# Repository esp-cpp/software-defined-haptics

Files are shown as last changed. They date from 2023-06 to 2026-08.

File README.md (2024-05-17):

# Software Defined Haptics

This project contains the MCAD and source files for a BLDC motor test stand,
designed to enable running various experiments in openloop control, closed loop
control, and user interface / haptics using a small BLDC motor that's commonly
used in camera gimbals.

The code supports running on the custom BLDC Test Stand (`TinyS3 Test Stand`),
as well as on the `MotorGo-Mini`. You can select which hardware you want to run
on via `menuconfig`.

## Hardware

Either:
* TinyS3 Test Stand:
  * TinyS3
  * BLDC Motor (I used [these A and B motors](https://www.aliexpress.us/item/3256802907900422.html) from aliexpress)
  * MT6701 Magnetic Encoder Breakout (I used [this purple one (color B)](https://www.aliexpress.us/item/3256804851103272.html) from aliexpress)
  * TMC6300 BOB
  * Mini solderless breadboard
  * 3d printed test stand enclosure (.stl and source files in the [mcad](./mcad) directory)
  * Benchtop power supply (currently running at 5V 1A so many things should work)
or:
* MotorGo-Mini

### Configure

``` 
idf.py menuconfig
```

Select which hardware you are building and deploying to.

### Build and Flash

Build the project and flash it to the board, then run monitor tool to view serial output:

```
idf.py -p PORT flash monitor
```

(Replace PORT with the name of the serial port to use.)

(To exit the serial monitor, type ``Ctrl-]``.)

See the Getting Started Guide for full steps to configure and use ESP-IDF to build projects.

## Output

The haptics (detent configuration, click/buzz) can be configured dynamically at
run-time using the provided CLI, see screenshot below:

CleanShot 2023-06-23 at 13 23 44

https://github.com/esp-cpp/bldc_test_stand/assets/213467/d0974dc0-430a-4957-bd6d-f9841209f21d

As you can see, the cli also allows you to start and stop the haptic engine
(default is off when the program starts) and allows you to query the position of
the motor based on the current detent config. The default detent config is the
unbounded_no_detents configuration.

For more information, see the documentation or the original PR:
https://github.com/esp-cpp/espp/pull/60

Some examples:

### coarse values strong detents (best with sound)

https://github.com/esp-cpp/espp/assets/213467/a256b401-6e45-4284-89c7-2dec9a49daa7

### magnetic detents (best with sound)

https://github.com/esp-cpp/espp/assets/213467/ab1ace5c-f967-4cfc-b304-7736fdb35bcb

### On / Off Strong Detents (best with sound)

https://github.com/esp-cpp/espp/assets/213467/038d79b1-7cd9-4af9-b7e8-1b4daf6a363a

### Multi-rev no detents

https://github.com/esp-cpp/espp/assets/213467/2af81edb-67b8-488b-ae7a-3549be36b8cc

## Troubleshooting

Make sure to run the code once with `zero_electrical_offset` set to 0 so that
the motor will go through a calibration / zero offset routine. At the end of
this startup routine it will print the measured zero electrical offset that you
can then provide within the code, at which point it will not need to run the
calibration routine.

You must run this calibration any time you change your hardware configuration
(such as by remounting your motor, magnet, encoder chip).

## Code Breakdown

This example encapsulates the board support packages into one of two components:
* `espp::TinyS3TestStand` (in this repo)
* `espp::MotorGoMini` (in espp)

These components build complex haptic behavior using the
following components:

* `espp::Mt6701`
* `espp::BldcDriver`
* `espp::BldcMotor`
* `espp::BldcHaptics`
* `espp::I2c`

You combine the `Mt6701` and `BldcDriver` together when creating the `BldcMotor`
and then simply pass the `BldcMotor` to the `BldcHaptics` component. At that
point, you only have to interface to the `BldcHaptics` to read the input
position or reconfigure the haptics.

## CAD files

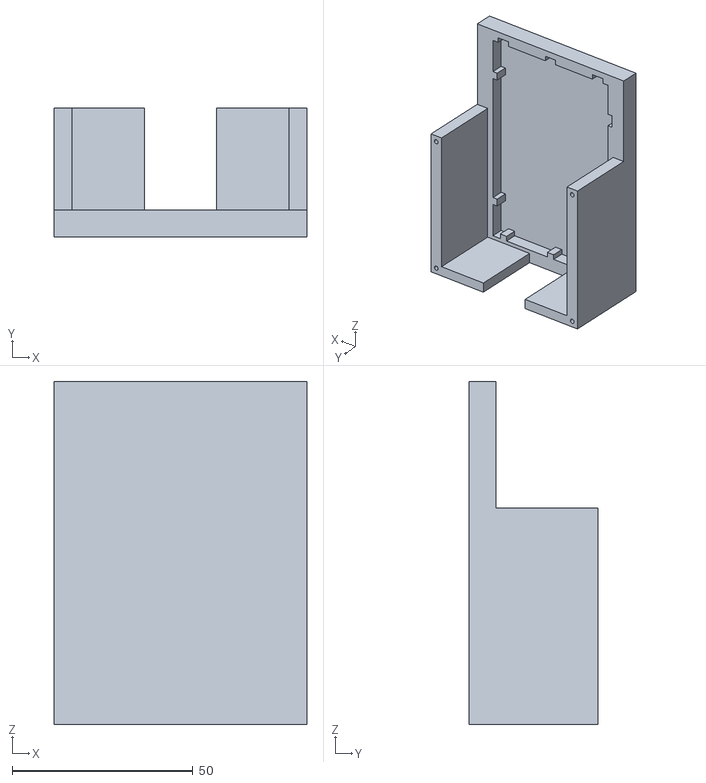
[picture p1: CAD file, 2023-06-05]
mcad/bldc_test_stand_bottom.stl
70.0 x 35.8 x 95.0

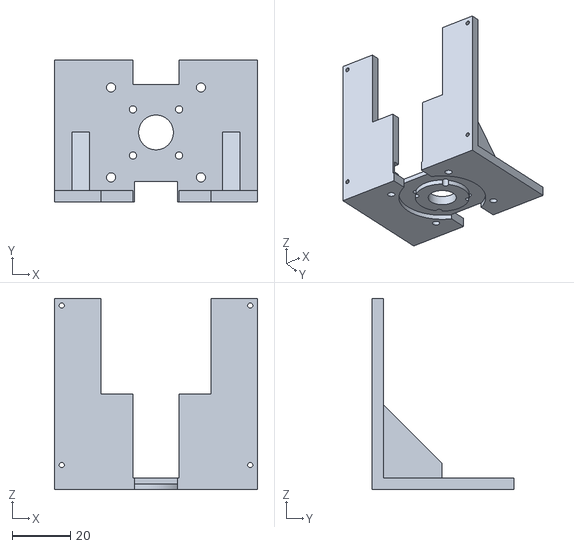
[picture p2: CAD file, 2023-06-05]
mcad/bldc_test_stand_top.stl
70.0 x 49.0 x 66.0

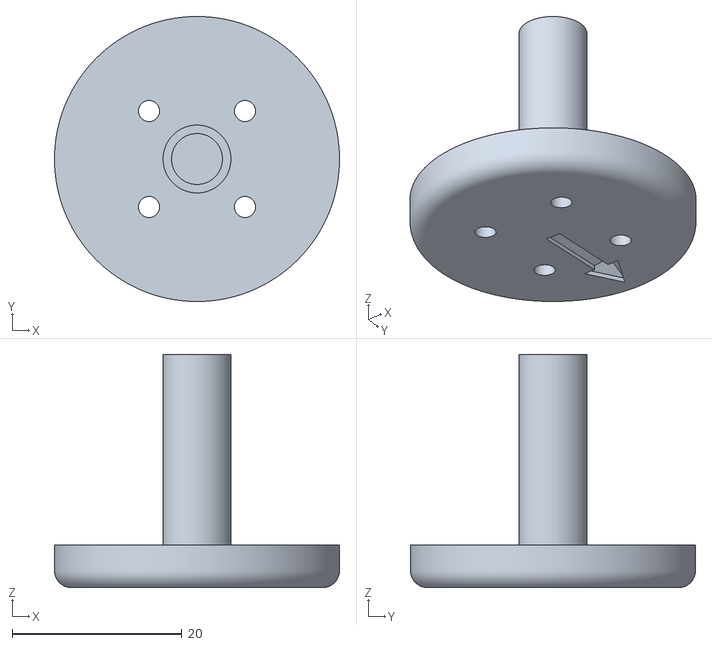
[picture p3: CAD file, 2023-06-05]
mcad/bldc_motor_cap.stl
33.6 x 33.6 x 27.5

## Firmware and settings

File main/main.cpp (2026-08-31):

#include <chrono>
#include <vector>

#include "bldc_haptics.hpp"
#include "cli.hpp"

#include "motorgo-mini.hpp"
#include "tinys3_test_stand.hpp"

using namespace std::chrono_literals;

extern "C" void app_main(void) {
  espp::Logger logger({.tag = "BLDC Test Stand", .level = espp::Logger::Verbosity::DEBUG});

  logger.info("Bootup");

#if CONFIG_EXAMPLE_HARDWARE_MOTORGO_MINI
#pragma message("Using MotorGo Mini hardware configuration")
  logger.info("Using MotorGo Mini hardware configuration");
  // we don't want to init both motors, so we'll pass in auto_init=false
  auto &motorgo_mini = espp::MotorGoMini::get();

#if CONFIG_EXAMPLE_BLDC_MOTOR_1
#pragma message("Using MotorGo Mini Motor 1")
  logger.info("Configuring Motor 1");
  auto motor_config = motorgo_mini.default_motor1_config;
#elif CONFIG_EXAMPLE_BLDC_MOTOR_2
#pragma message("Using MotorGo Mini Motor 2")
  logger.info("Configuring Motor 2");
  auto motor_config = motorgo_mini.default_motor2_config;
#else
#error "No motor selected"
#endif

  // velocity PID config:
  motor_config.velocity_pid_config.kp = 0.010f;
  motor_config.velocity_pid_config.ki = 0.100f;
  motor_config.velocity_pid_config.kd = 0.000f;
  // angle PID config:
  motor_config.angle_pid_config.kp = 5.000f;
  motor_config.angle_pid_config.ki = 1.000f;
  motor_config.angle_pid_config.kd = 0.000f;

#if CONFIG_EXAMPLE_BLDC_MOTOR_1
  motorgo_mini.init_motor_channel_1(motor_config);
  auto motor = motorgo_mini.motor1();
#elif CONFIG_EXAMPLE_BLDC_MOTOR_2
  motorgo_mini.init_motor_channel_2(motor_config);
  auto motor = motorgo_mini.motor2();
#else
#error "No motor selected"
#endif

  using BldcHaptics = espp::BldcHaptics<espp::MotorGoMini::BldcMotor>;
#elif CONFIG_EXAMPLE_HARDWARE_TEST_STAND
#pragma message("Using TinyS3 Test Stand hardware configuration")
  logger.info("Using TinyS3 Test Stand hardware configuration");
  auto &test_stand = espp::TinyS3TestStand::get();
  auto motor_config = test_stand.default_motor_config;
  test_stand.init_motor(motor_config);
  auto motor = test_stand.motor();
  using BldcHaptics = espp::BldcHaptics<espp::TinyS3TestStand::BldcMotor>;
#else
#error "No hardware configuration selected"
#endif

  auto haptic_motor = BldcHaptics(BldcHaptics::Config{.motor = motor,
                                                      .kp_factor = 2,
                                                      .kd_factor_min = 0.01,
                                                      .kd_factor_max = 0.04,
                                                      .log_level = espp::Logger::Verbosity::WARN});

  // set the default detent config to be unbounded no detents so that if
  haptic_motor.update_detent_config(espp::detail::UNBOUNDED_NO_DETENTS);

  auto root_menu = std::make_unique<cli::Menu>("haptics", "Haptic configuration menu");
  root_menu->Insert(
      "start",
      [&](std::ostream &out) {
        if (!haptic_motor.is_running()) {
          out << "Starting motor!\n";
          haptic_motor.start();
        } else {
          out << "Motor already running!\n";
        }
      },
      "Start the motor");
  root_menu->Insert(
      "stop",
      [&](std::ostream &out) {
        if (haptic_motor.is_running()) {
          out << "Stopping motor!\n";
          haptic_motor.stop();
        } else {
          out << "Motor already stopped!\n";
        }
      },
      "Stop the motor");
  root_menu->Insert(
      "position",
      [&](std::ostream &out) {
        out << "Current position: " << haptic_motor.get_position() << "\n";
      },
      "Print the current position of the haptic motor");
  root_menu->Insert(
      "shaft_angle",
      [&](std::ostream &out) {
        out << "Current shaft angle: " << motor->get_shaft_angle() << " radians\n";
      },
      "Print the current position of the haptic motor");
  root_menu->Insert(
      "electrical_angle",
      [&](std::ostream &out) {
        out << "Current electrical angle: " << motor->get_electrical_angle() << " radians\n";
      },
      "Print the current position of the haptic motor");
  root_menu->Insert(
      "unbounded_no_detents",
      [&](std::ostream &out) {
        out << "Setting to unbounded no detents!\n";
        haptic_motor.update_detent_config(espp::detail::UNBOUNDED_NO_DETENTS);
      },
      "Set the haptic config to unbounded no detents");
  root_menu->Insert(
      "bounded_no_detents",
      [&](std::ostream &out) {
        out << "Setting to bounded no detents!\n";
        haptic_motor.update_detent_config(espp::detail::BOUNDED_NO_DETENTS);
      },
      "Set the haptic config to bounded no detents");
  root_menu->Insert(
      "multi_rev_no_detents",
      [&](std::ostream &out) {
        out << "Setting to multi rev no detents!\n";
        haptic_motor.update_detent_config(espp::detail::MULTI_REV_NO_DETENTS);
      },
      "Set the haptic config to multi rev no detents");
  root_menu->Insert(
      "on_off_strong_detents",
      [&](std::ostream &out) {
        out << "Setting to on off strong detents!\n";
        haptic_motor.update_detent_config(espp::detail::ON_OFF_STRONG_DETENTS);
      },
      "Set the haptic config to on off strong detents");
  root_menu->Insert(
      "coarse_values_strong_detents",
      [&](std::ostream &out) {
        out << "Setting to coarse values strong detents!\n";
        haptic_motor.update_detent_config(espp::detail::COARSE_VALUES_STRONG_DETENTS);
      },
      "Set the haptic config to coarse values strong detents");
  root_menu->Insert(
      "fine_values_no_detents",
      [&](std::ostream &out) {
        out << "Setting to fine values no detents!\n";
        haptic_motor.update_detent_config(espp::detail::FINE_VALUES_NO_DETENTS);
      },
      "Set the haptic config to fine values no detents");
  root_menu->Insert(
      "fine_values_with_detents",
      [&](std::ostream &out) {
        out << "Setting to fine values with detents!\n";
        haptic_motor.update_detent_config(espp::detail::FINE_VALUES_WITH_DETENTS);
      },
      "Set the haptic config to fine values with detents");
  root_menu->Insert(
      "magnetic_detents",
      [&](std::ostream &out) {
        out << "Setting to magnetic detents!\n";
        haptic_motor.update_detent_config(espp::detail::MAGNETIC_DETENTS);
      },
      "Set the haptic config to magnetic detents");
  root_menu->Insert(
      "return_to_center_with_detents",
      [&](std::ostream &out) {
        out << "Setting to return to center with detents!\n";
        haptic_motor.update_detent_config(espp::detail::RETURN_TO_CENTER_WITH_DETENTS);
      },
      "Set the haptic config to return to center with detents");
  root_menu->Insert(
      "click",
      // cppcheck-suppress constParameterReference
      [&](std::ostream &out, float strength) {
        strength = std::clamp(strength, 0.0f, 10.0f);
        espp::detail::HapticConfig config{
            .strength = strength,
            .frequency = 0.0f, // TODO: unused
            .duration = 1ms,   // TODO: unused
        };
        haptic_motor.play_haptic(config);
      },
      "Play a haptic click / buzz with the given strength (suggested range 1.0 - 5.0)");
  root_menu->Insert(
      "color",
      [](std::ostream &out) {
        out << "Colors ON\n";
        cli::SetColor();
      },
      "Enable colors in the cli");
  root_menu->Insert(
      "nocolor",
      [](std::ostream &out) {
        out << "Colors OFF\n";
        cli::SetNoColor();
      },
      "Disable colors in the cli");

  cli::Cli cli(std::move(root_menu));
  // turn the colors on by default :)
  cli::SetColor();
  // add an exit action to stop the motor when the cli exits
  cli.ExitAction([&](auto &out) {
    out << "Exiting menu and disabling haptics!\n";
    haptic_motor.stop();
    out << "Goodbye and thanks for all the fish.\n";
  });

  espp::Cli input(cli);
  input.SetInputHistorySize(10);
  input.Start();

  // if we've gotten here the cli has finished its session
}

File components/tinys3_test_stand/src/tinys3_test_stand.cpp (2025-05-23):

#include "tinys3_test_stand.hpp"

using namespace espp;

TinyS3TestStand::TinyS3TestStand()
    : BaseComponent("TinyS3 Test Stand") {}

void TinyS3TestStand::init_motor(const TinyS3TestStand::BldcMotor::Config &motor_config,
                                 const TinyS3TestStand::DriverConfig &driver_config) {
  bool run_task = true;
  std::error_code ec;
  // make the encoder
  encoder_ = std::make_shared<Encoder>(encoder_config_);
  // initialize the encoder
  encoder_->initialize(run_task, ec);
  if (ec) {
    logger_.error("Could not initialize encoder: {}", ec.message());
    return;
  }

  // copy the config data for the driver
  motor_driver_config_.power_supply_voltage = driver_config.power_supply_voltage;
  motor_driver_config_.limit_voltage = driver_config.limit_voltage;
  // make the driver
  motor_driver_ = std::make_shared<BldcDriver>(motor_driver_config_);

  // now copy the relevant configs into the motor config
  auto motor_config_copy = motor_config;
  motor_config_copy.driver = motor_driver_;
  motor_config_copy.sensor = encoder_;
  // now make the motor
  motor_ = std::make_shared<BldcMotor>(motor_config_copy);
  motor_->initialize();
}

std::shared_ptr<TinyS3TestStand::Encoder> TinyS3TestStand::encoder() { return encoder_; }

void TinyS3TestStand::reset_encoder_accumulator() { encoder_->reset_accumulator(); }

std::shared_ptr<espp::BldcDriver> TinyS3TestStand::motor_driver() { return motor_driver_; }

std::shared_ptr<TinyS3TestStand::BldcMotor> TinyS3TestStand::motor() { return motor_; }

TinyS3TestStand::VelocityFilter &TinyS3TestStand::motor_velocity_filter() {
  return motor_velocity_filter_;
}

TinyS3TestStand::AngleFilter &TinyS3TestStand::motor_angle_filter() { return motor_angle_filter_; }

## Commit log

2023-06-05 feat: initial commit modified from bldc_haptics example
    [bldc_motor_cap.stl, bldc_test_stand_bottom.stl, bldc_test_stand_top.stl]
2023-06-23 feat(cli): added cli * Updated espp submodule to have latest cli with support for s3 * Added cli dependency * Updated sdkconfig to turn on exceptions (for cli) and to set default console to be USB-SE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
2023-06-23 bugfix(haptics): enable repeated start/stop * Update espp submodule for bldc control bugfix - enabling repeated enable/disable * Added commands for getting the shaft angle and electical angle of the 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
    [main.cpp]
2023-08-01 submodule(espp): update * Updated espp submodule with bldc driver level fix.
2023-08-01 feat(main): always calibrate * Updated main code to always calibrate sensor direction and electrical angle
2023-08-01 submodule(espp): update * Updated espp submodule to have latest driver/motor code to remove spurious warnings and leverage mcpwm fault handling
2023-11-06 feat(peripherals): updated peripheral api and use new espp::I2c class * Removed old esp-idf i2c configuration in favor of new espp::I2c class * Updated function binding for magnetic encoder periphera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
    [main.cpp]
2024-05-17 Feature/motorgo support (#10)
    * update to latest motorgo api
    * feat: add component for tinys3 test stand
    * feat: update to allow kconfig to switch between motorgo-mini and tinys3 test stand hardware. Simplified main code accordingly
    * update readme.
2025-05-23 chore: Update to latest espp, use idf-component-manager (#12)
    * chore: Update to latest espp, use idf-component-manager
    * fix sa
    * update to latest
    * fix build
    [main.cpp, tinys3_test_stand.cpp]
2026-06-07 feat: Update motorgo configuration to allow selection of which motor to use (#15)
    * feat: Update motorgo configuration to allow selection of which motor to use
    * make logs symmetric
2026-08-31 fix(test-stand): Fix missing motor init on test stand hardware (#16)
    [main.cpp]
